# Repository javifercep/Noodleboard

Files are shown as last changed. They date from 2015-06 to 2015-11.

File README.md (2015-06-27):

# Noodleboard
Arduino form factor board with USB 2.0 High speed based on STM32F405 MCU.
It has been developed for the [MuBA project](https://gitlab.euridies.com/javi/MuBA)

## Features
 * STM32F405RGT6 microcontroller featuring 32-bit ARM Cortex-M4F core, 1 MB Flash, 192 KB RAM in an LQFP64 package
 * Extension header fully compatible with Arduino™ form-factor
 * USB3300: USB OTG HS with micro-AB connector
 * Board power supply: through USB bus.
 * External application power supply: 3.3 V and 5 V
 * Four green user LEDs
 * Reset button
 * Headers for programming and debugging through SWD protocol

## [Pin map](pin-map)

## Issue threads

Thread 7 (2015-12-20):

Change USB connector footprint pinout

javifercep, 2015-12-20:
It is inverted

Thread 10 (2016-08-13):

Labels C4 and R5 are swapped

javifercep, 2016-08-13:
Next to the Oscillator of the USB circuit.
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

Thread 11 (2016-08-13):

Lables R22 & R23 are swaped

javifercep, 2016-08-13:
Bottom layer, next to SD connector.
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

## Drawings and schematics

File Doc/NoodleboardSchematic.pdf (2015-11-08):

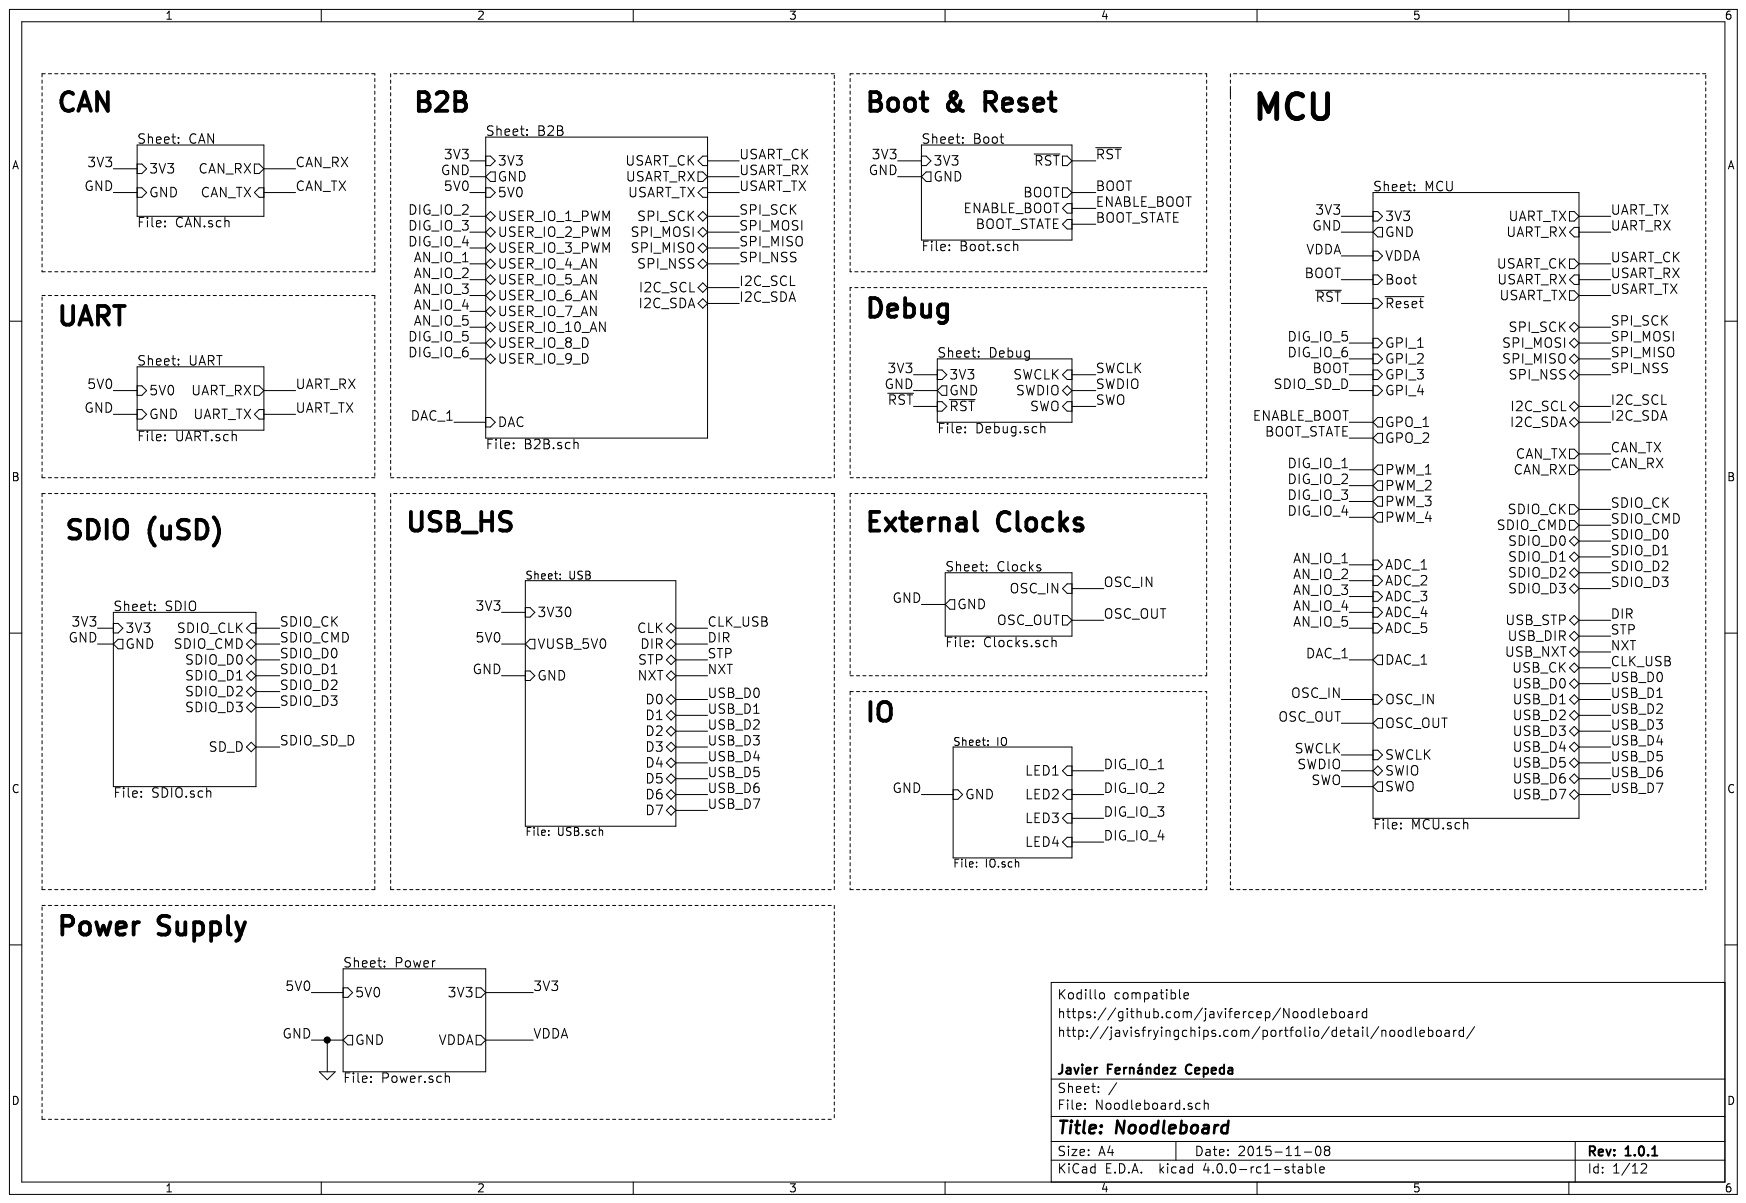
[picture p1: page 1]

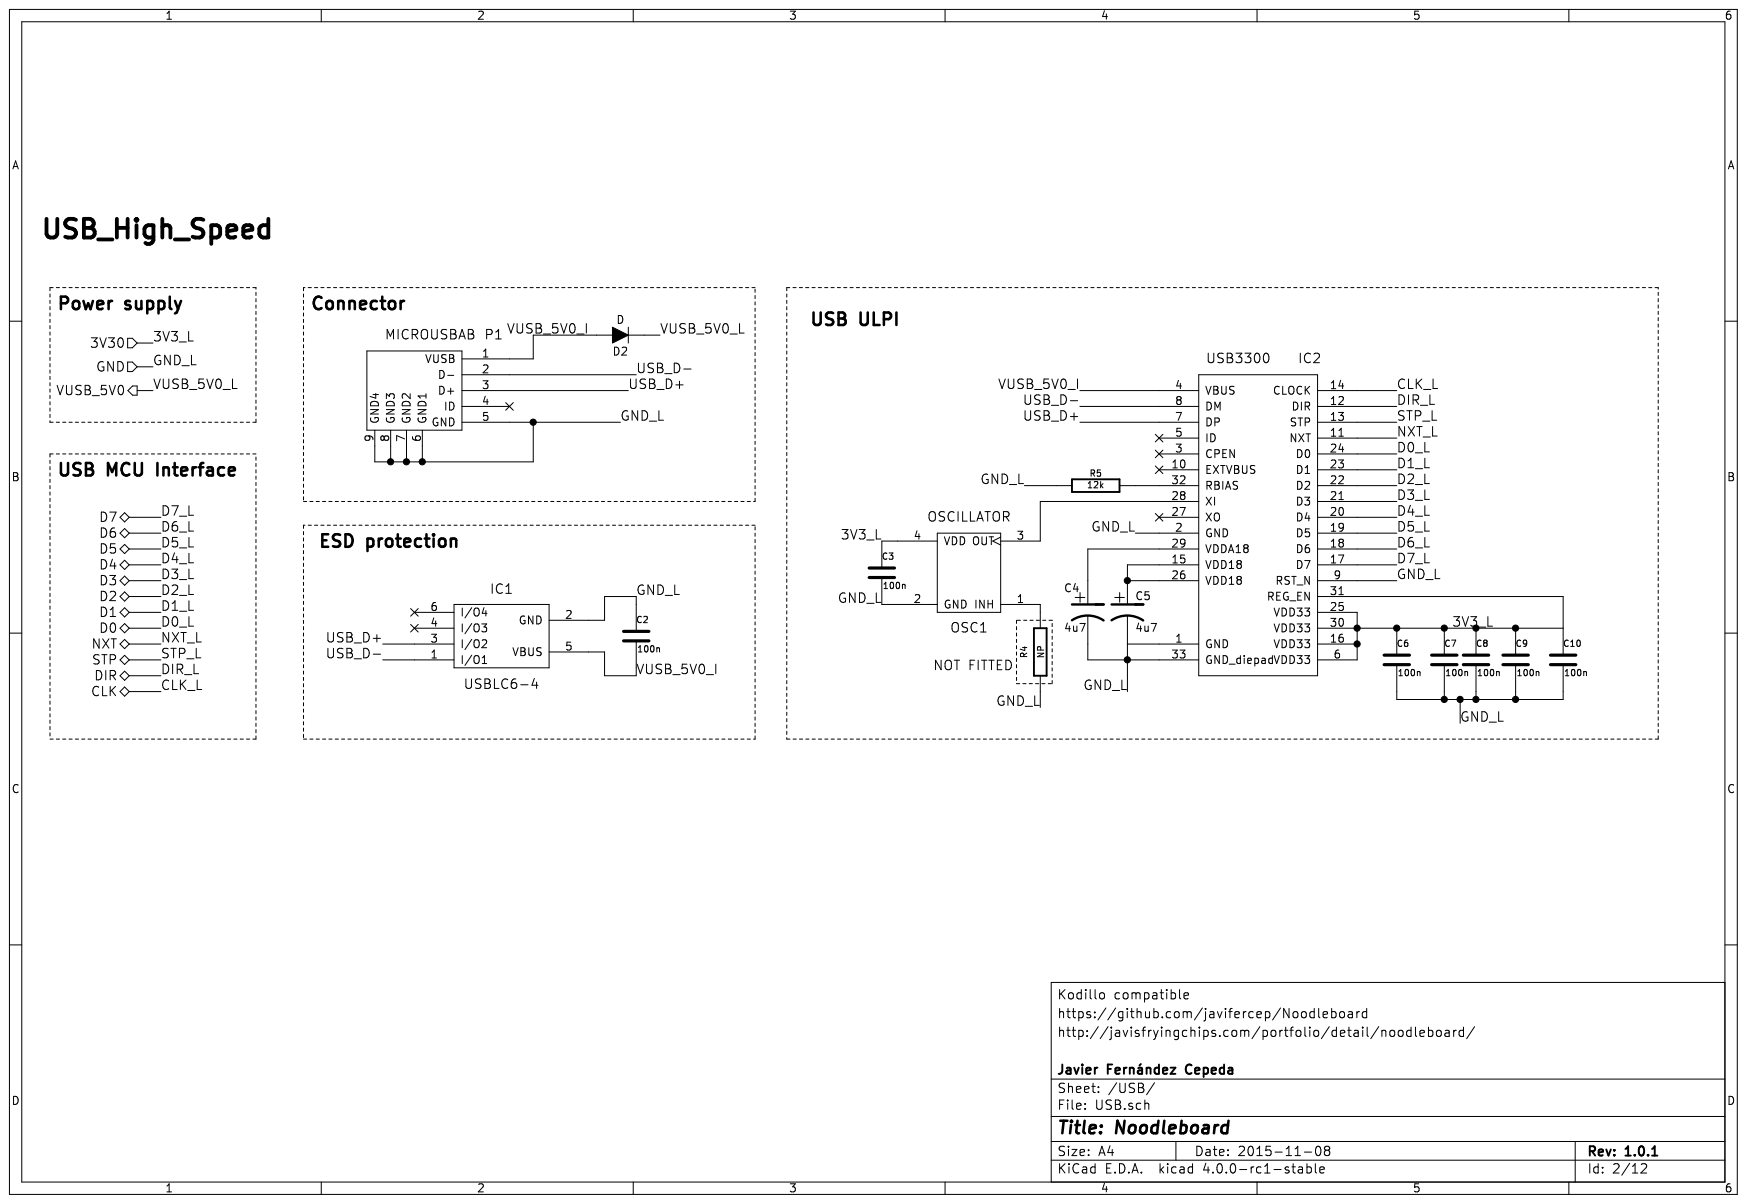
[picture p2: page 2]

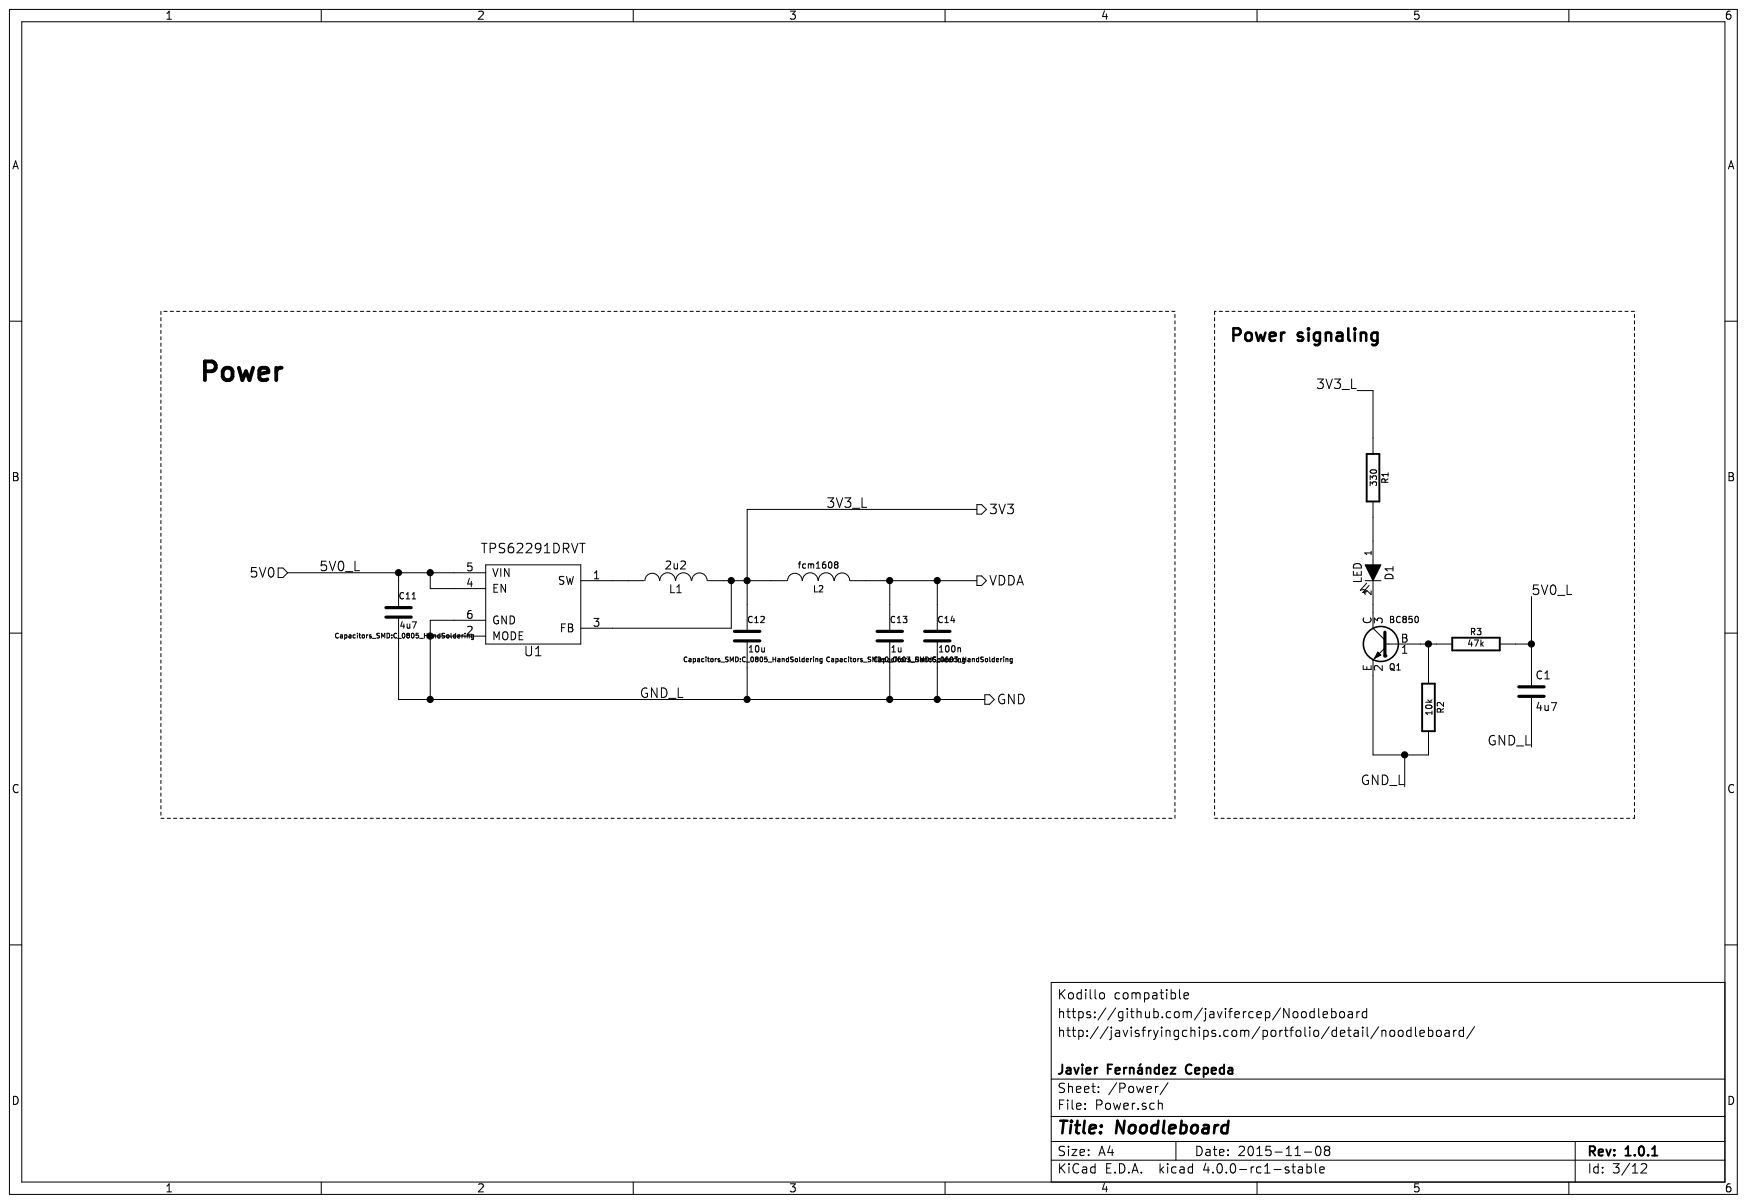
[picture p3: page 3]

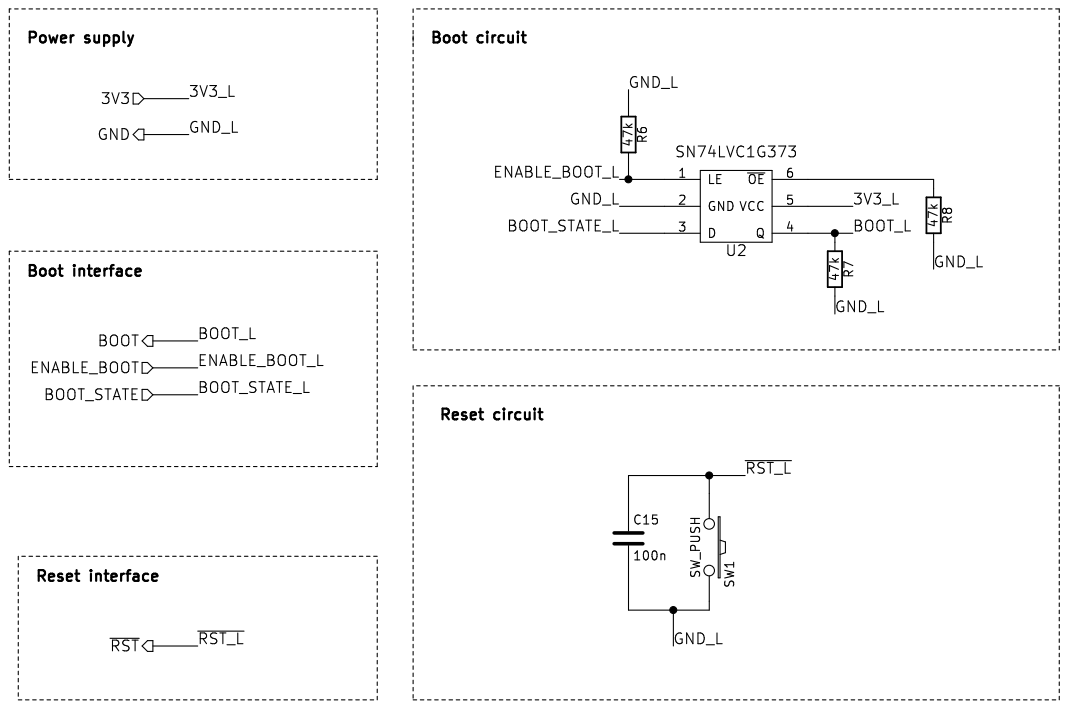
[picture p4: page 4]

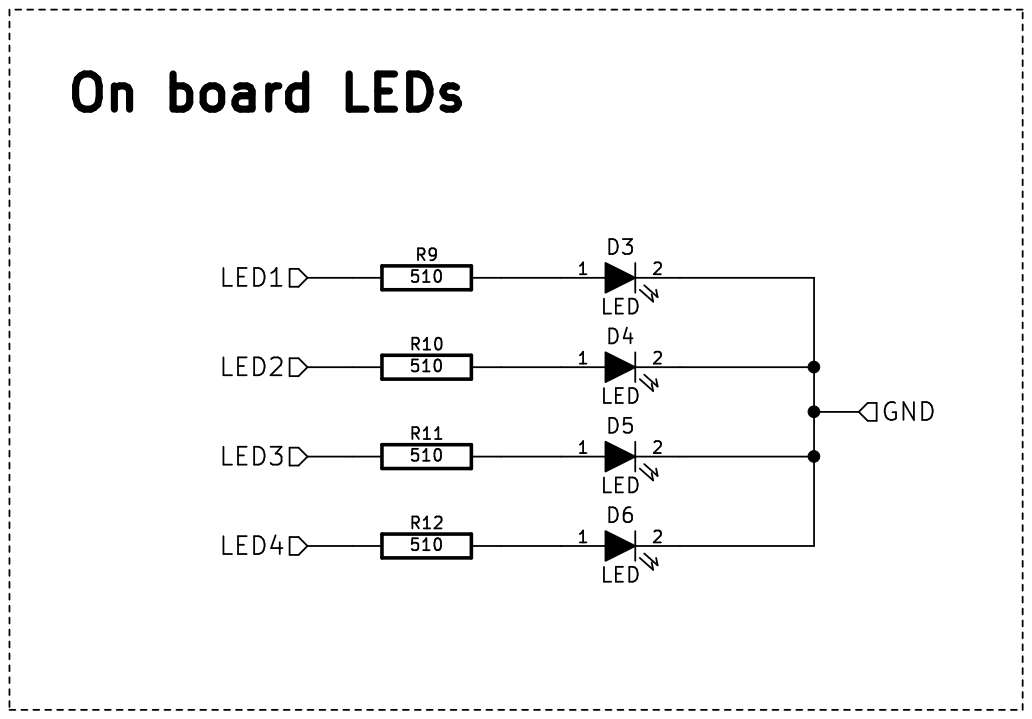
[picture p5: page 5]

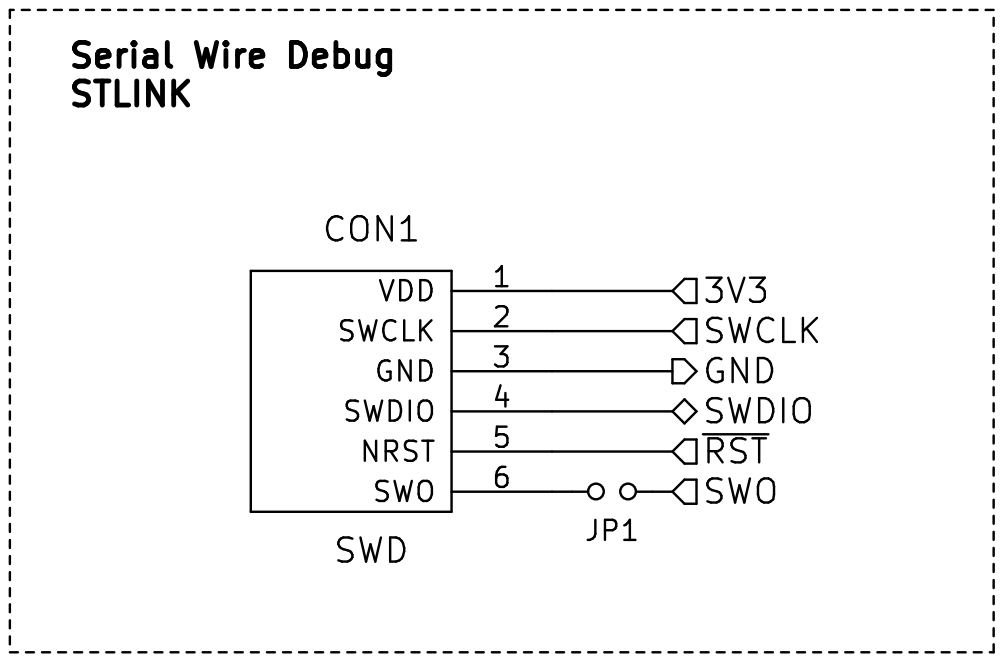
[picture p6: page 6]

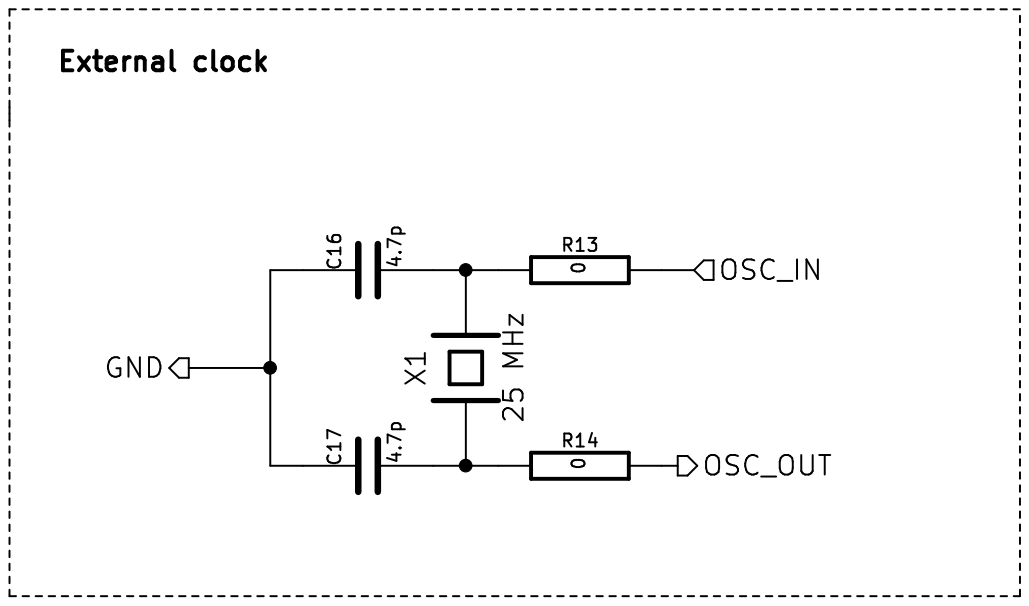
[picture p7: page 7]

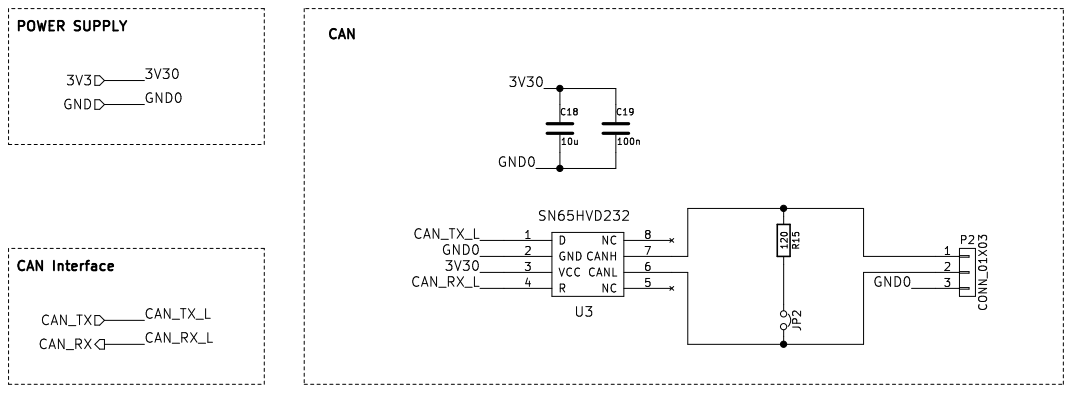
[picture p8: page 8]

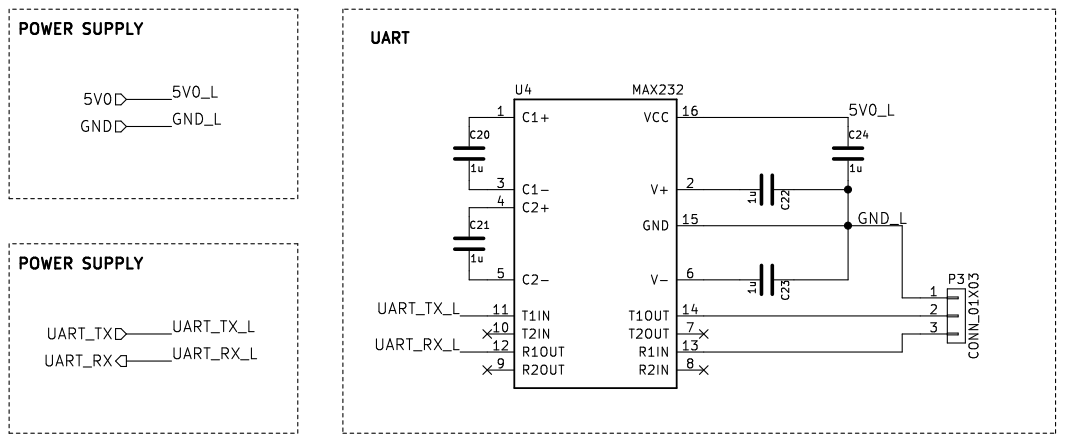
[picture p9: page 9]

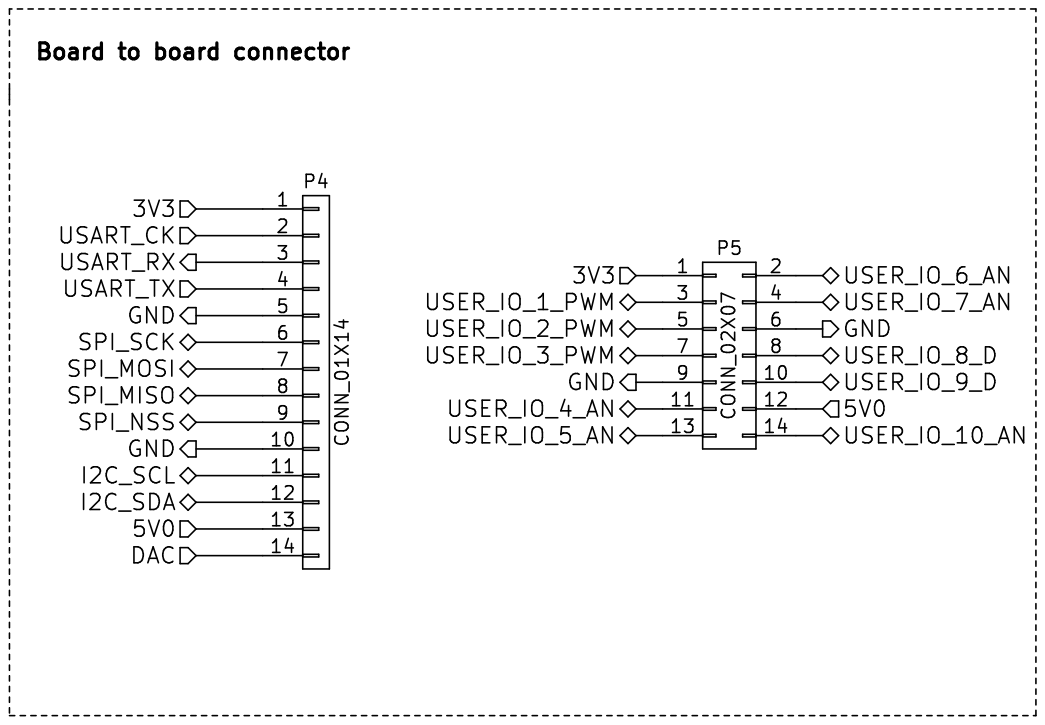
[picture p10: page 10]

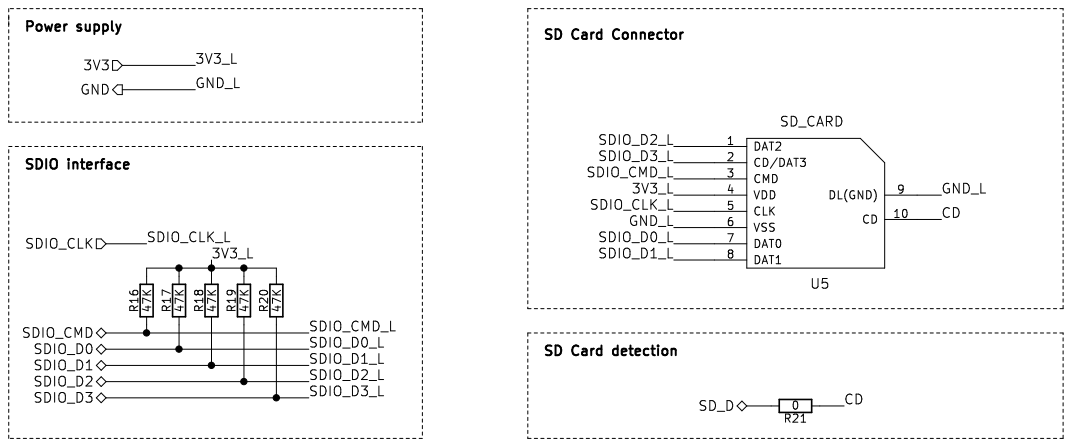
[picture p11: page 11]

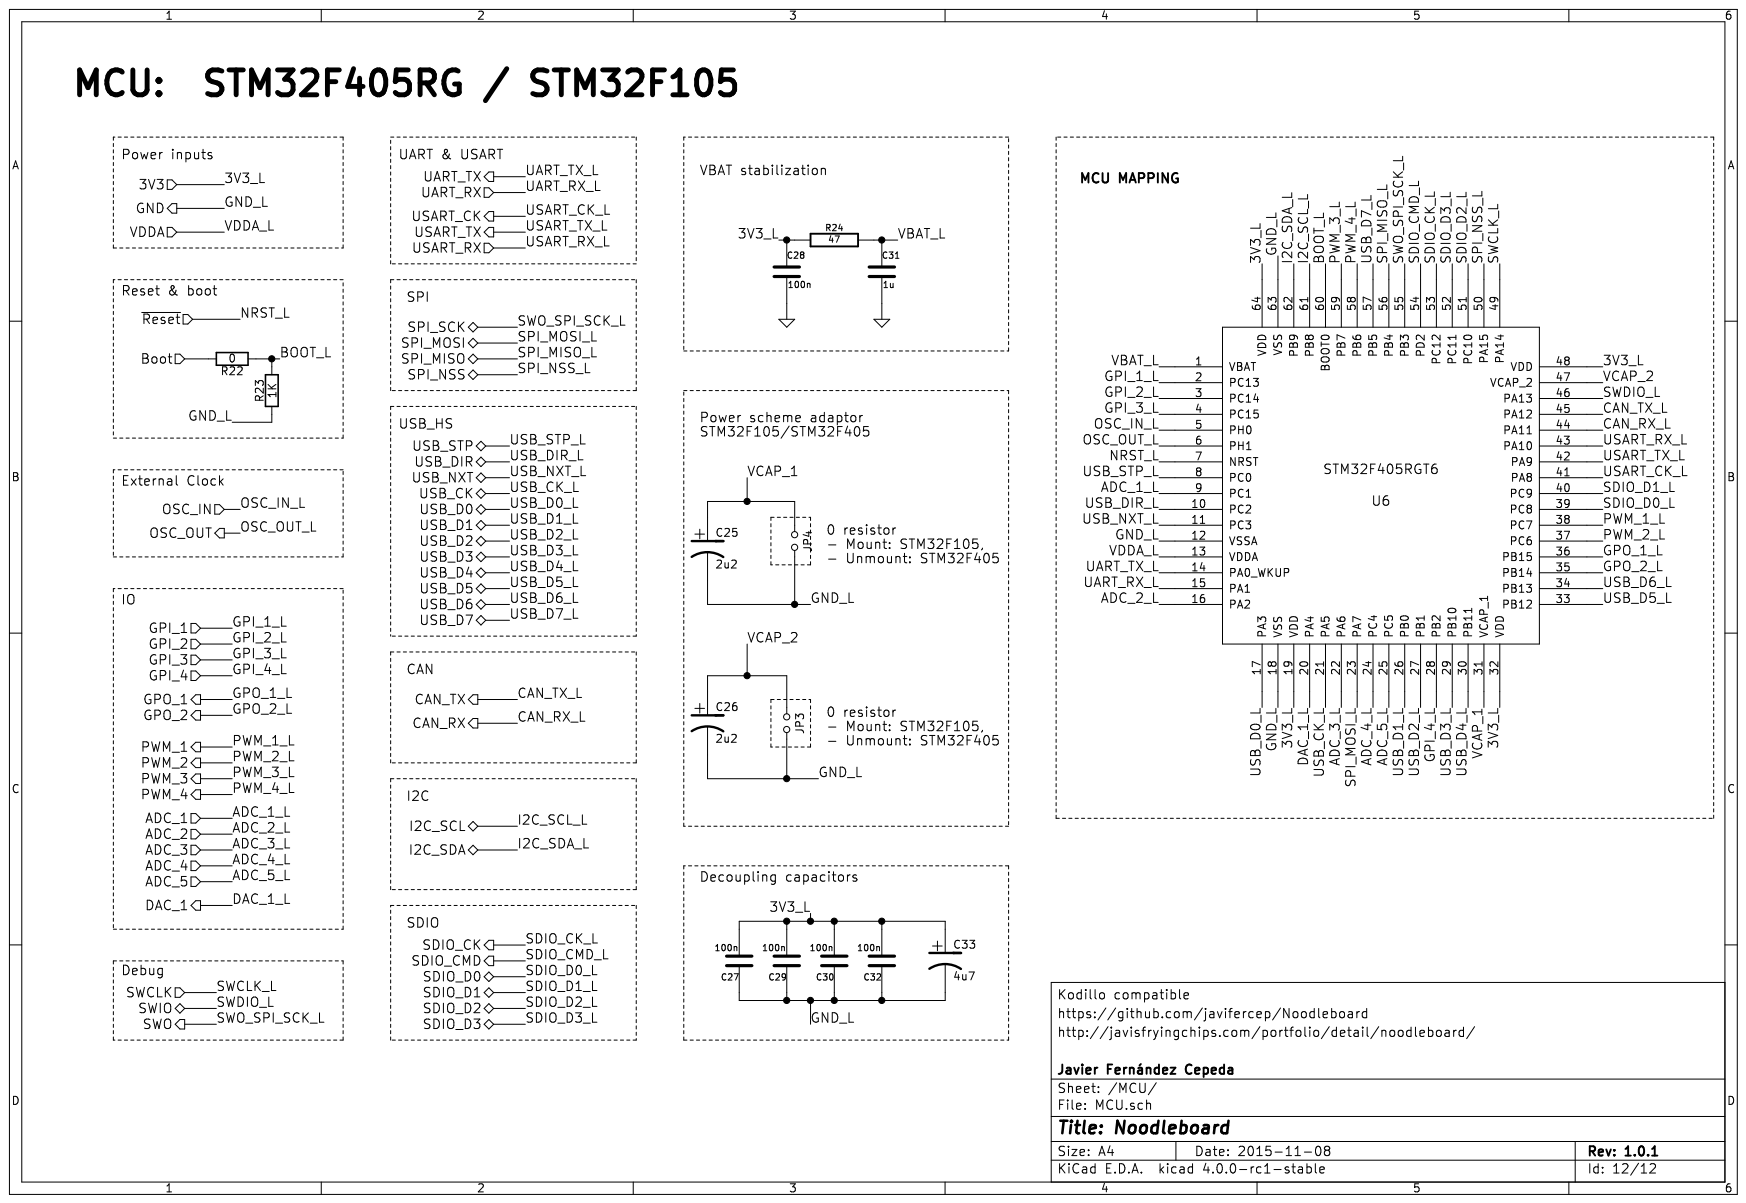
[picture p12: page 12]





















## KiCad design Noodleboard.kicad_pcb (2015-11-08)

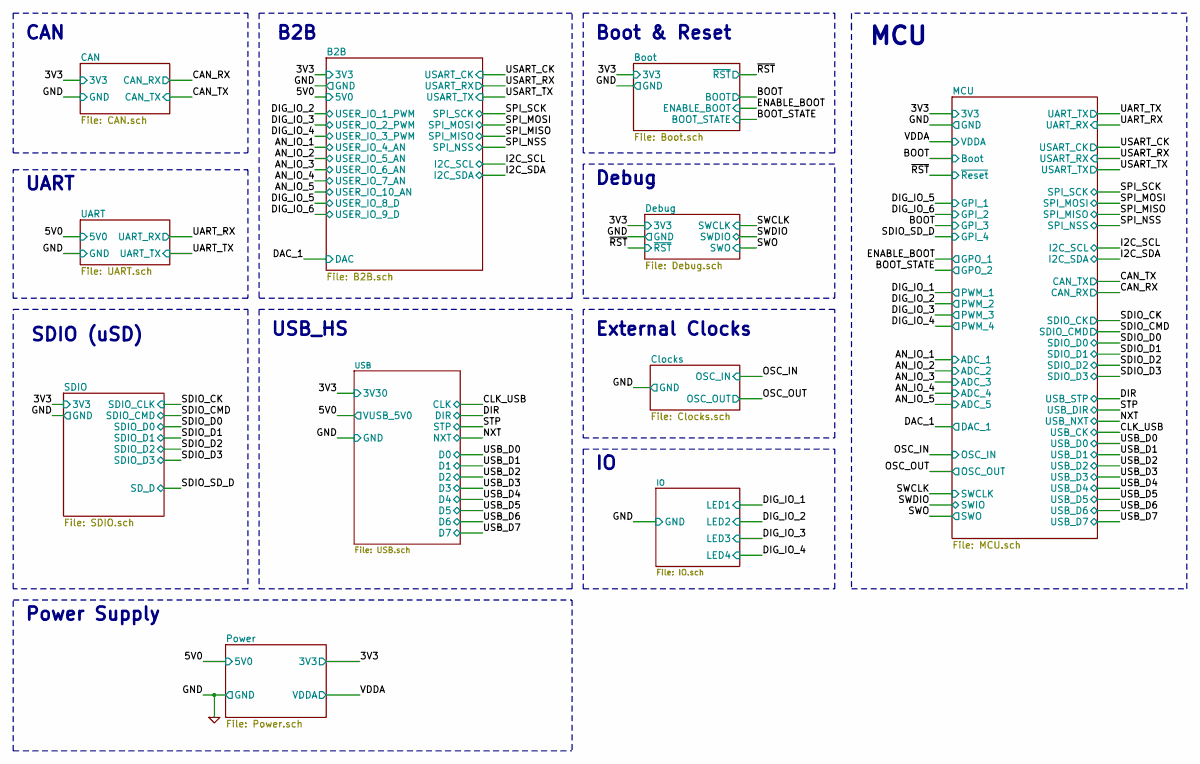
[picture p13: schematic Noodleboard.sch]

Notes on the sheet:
Power Supply
USB_HS
Debug
External Clocks
MCU
Boot & Reset
CAN
UART
B2B
SDIO (uSD)

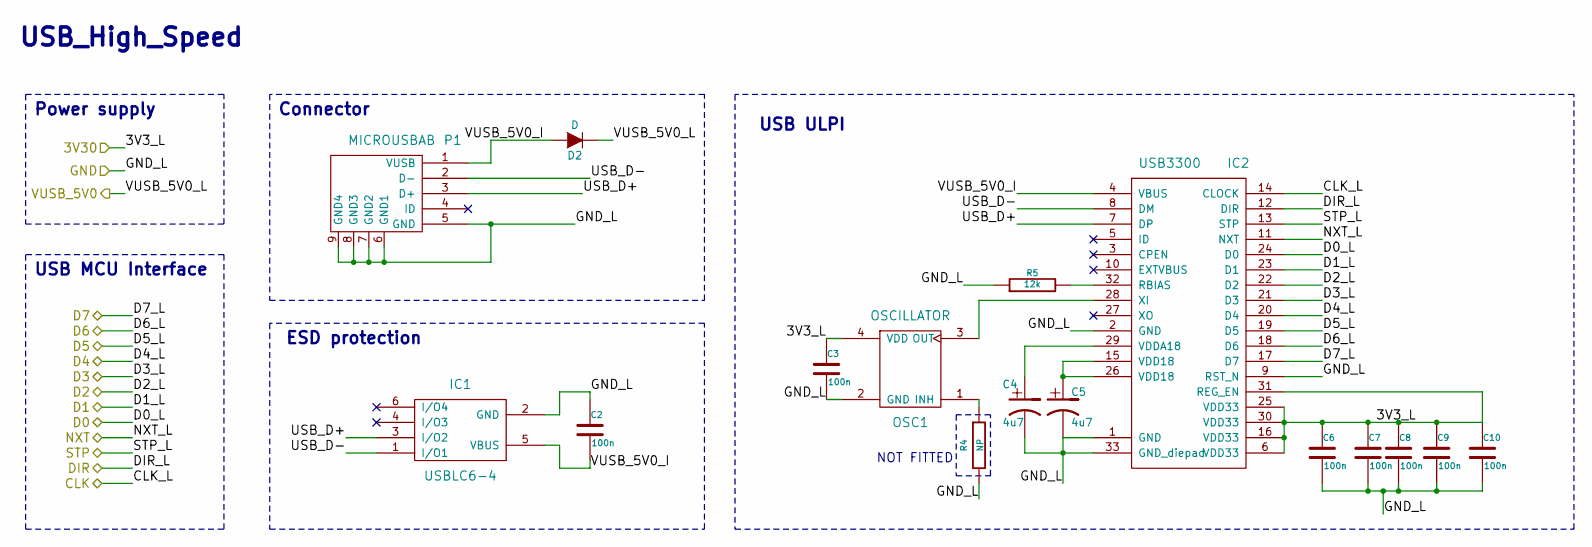
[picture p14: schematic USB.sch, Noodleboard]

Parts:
C2, C3, C6, C7, C8, C9, C10: 100n; C_0603_HandSoldering
C4, C5: 4u7; C_0805_HandSoldering
D2: D; SMA_Handsoldering
IC1: USBLC6-4; SOT-23-6
IC2: USB3300; QFN-32-1EP_5x5mm_Pitch0.5mm
OSC1: OSCILLATOR; 26MHZOSC
P1: MICROUSBAB; uUSB-AB
R4: NP; R_0603_HandSoldering
R5: 12k; R_0603_HandSoldering; Tolerancia 1%

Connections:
/B2B/3V3: C3.1, C6.1, C7.1, C8.1, C9.1, C10.1, IC2.6 (VDD33), IC2.16 (VDD33), IC2.25 (VDD33), IC2.30 (VDD33), IC2.31 (REG_EN), OSC1.4 (VDD); also elsewhere on the board
/B2B/5V0: D2.1 (K); also elsewhere on the board
/USB/CLK: IC2.14 (CLOCK); also elsewhere on the board
/USB/D0: IC2.24 (D0); also elsewhere on the board
/USB/D1: IC2.23 (D1); also elsewhere on the board
/USB/D2: IC2.22 (D2); also elsewhere on the board
/USB/D3: IC2.21 (D3); also elsewhere on the board
/USB/D4: IC2.20 (D4); also elsewhere on the board
/USB/D5: IC2.19 (D5); also elsewhere on the board
/USB/D6: IC2.18 (D6); also elsewhere on the board
/USB/D7: IC2.17 (D7); also elsewhere on the board
/USB/DIR: IC2.12 (DIR); also elsewhere on the board
/USB/NXT: IC2.11 (NXT); also elsewhere on the board
/USB/STP: IC2.13 (STP); also elsewhere on the board
/USB/USB_D+: IC1.3 (I/O2), IC2.7 (DP), P1.3 (D+)
/USB/USB_D-: IC1.1 (I/O1), IC2.8 (DM), P1.2 (D-)
/USB/VUSB_5V0_I: C2.2, D2.2 (A), IC1.5 (VBUS), IC2.4 (VBUS), P1.1 (VUSB)
GND: C2.1, C3.2, C4.2, C5.2, C6.2, C7.2, C8.2, C9.2, C10.2, IC1.2 (GND), IC2.1 (GND), IC2.2 (GND), IC2.9 (RST_N), IC2.33 (GND_diepad), OSC1.2 (GND), P1.5 (GND), P1.6 (GND1), P1.7 (GND2), P1.8 (GND3), P1.9 (GND4), R4.2, R5.1; also elsewhere on the board
unnamed: C4.1, IC2.29 (VDDA18)
unnamed: C5.1, IC2.15 (VDD18), IC2.26 (VDD18)
unnamed: IC2.28 (XI), OSC1.3 (OUT)
unnamed: IC2.32 (RBIAS), R5.2
unnamed: OSC1.1 (INH), R4.1

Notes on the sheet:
Power supply
USB_High_Speed
NOT FITTED
Connector
ESD protection
USB MCU Interface
USB ULPI

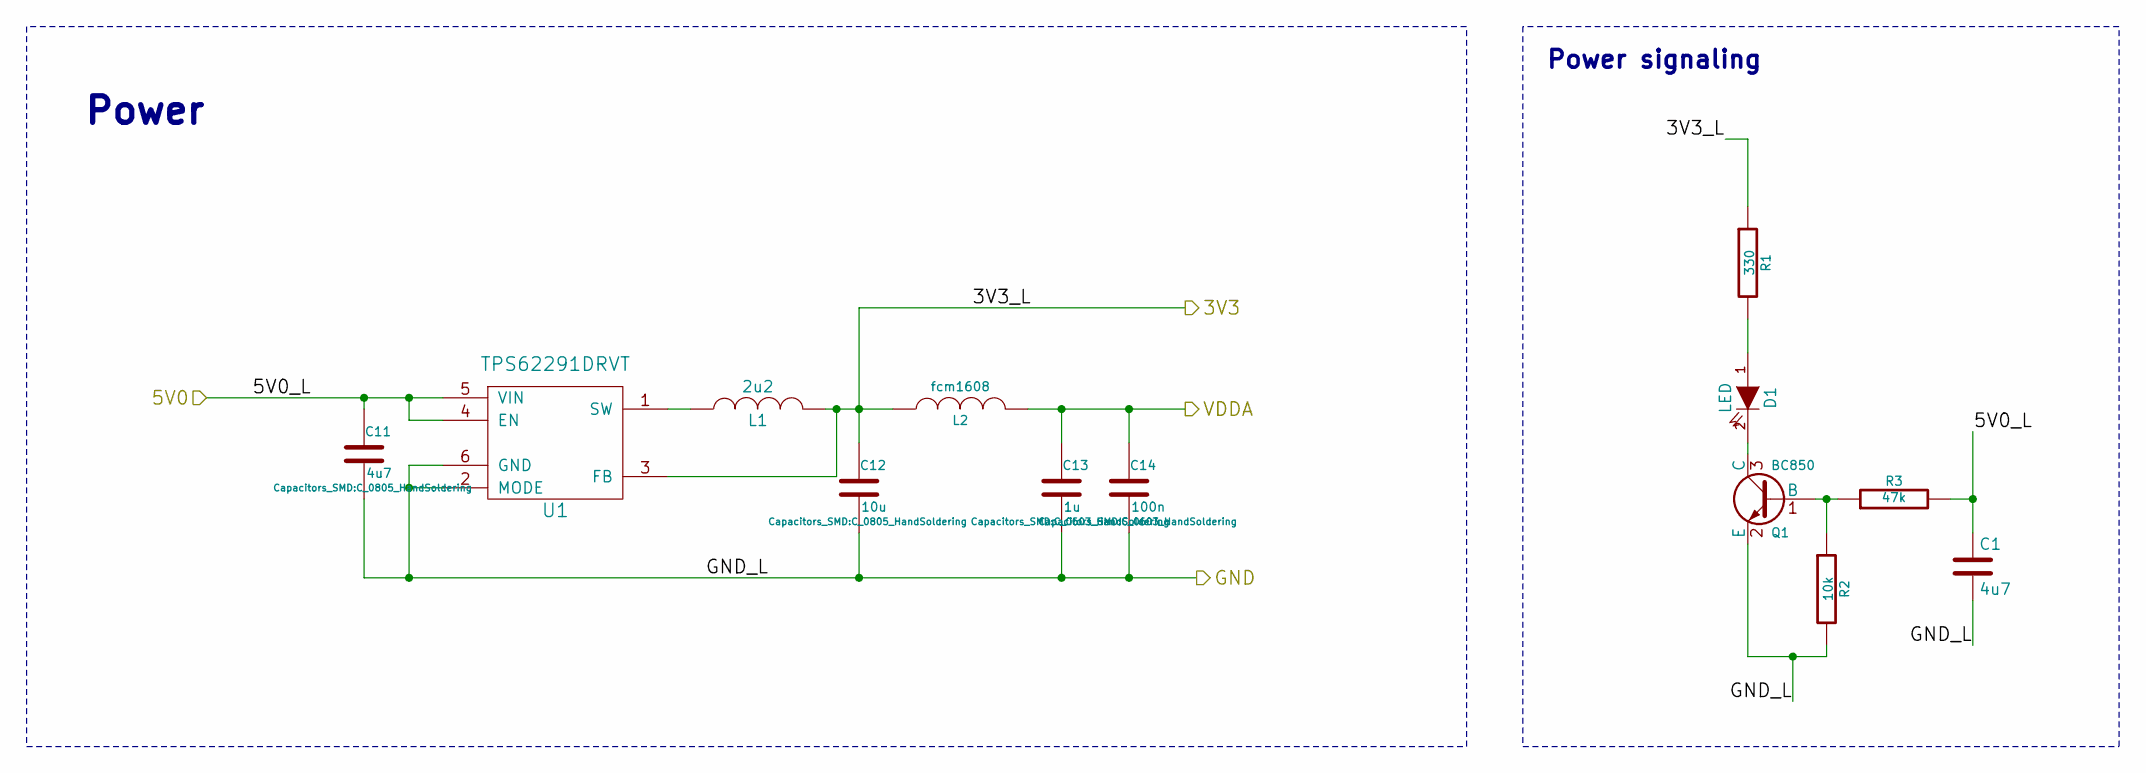
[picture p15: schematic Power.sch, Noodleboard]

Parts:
C1: 4u7; C_0805_HandSoldering
C11: 4u7; C_0805_HandSoldering; Part Number GRM188R60J475KE19D
C12: 10u; C_0805_HandSoldering; Part Number C1608X5R0J106M
C13: 1u; C_0603_HandSoldering
C14: 100n; C_0603_HandSoldering
D1: LED; LED-0805
L1: 2u2; SMD_1008; Part Number 74479887222A
L2: fcm1608; R_0603_HandSoldering
Q1: BC850; SOT-23_Handsoldering
R1: 330; R_0603_HandSoldering
R2: 10k; R_0603_HandSoldering
R3: 47k; R_0603_HandSoldering
U1: TPS62291DRVT; S-PWSON-N6

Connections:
/B2B/3V3: C12.1, L1.2, L2.1, R1.1, U1.3 (FB); also elsewhere on the board
/B2B/5V0: C1.1, C11.1, R3.2, U1.4 (EN), U1.5 (VIN); also elsewhere on the board
/MCU/VDDA: C13.1, C14.1, L2.2; also elsewhere on the board
GND: C1.2, C11.2, C12.2, C13.2, C14.2, Q1.2 (E), R2.2, U1.2 (MODE), U1.6 (GND); also elsewhere on the board
unnamed: D1.1 (A), R1.2
unnamed: D1.2 (K), Q1.3 (C)
unnamed: L1.1, U1.1 (SW)
unnamed: Q1.1 (B), R2.1, R3.1

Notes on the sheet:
Power
Power signaling

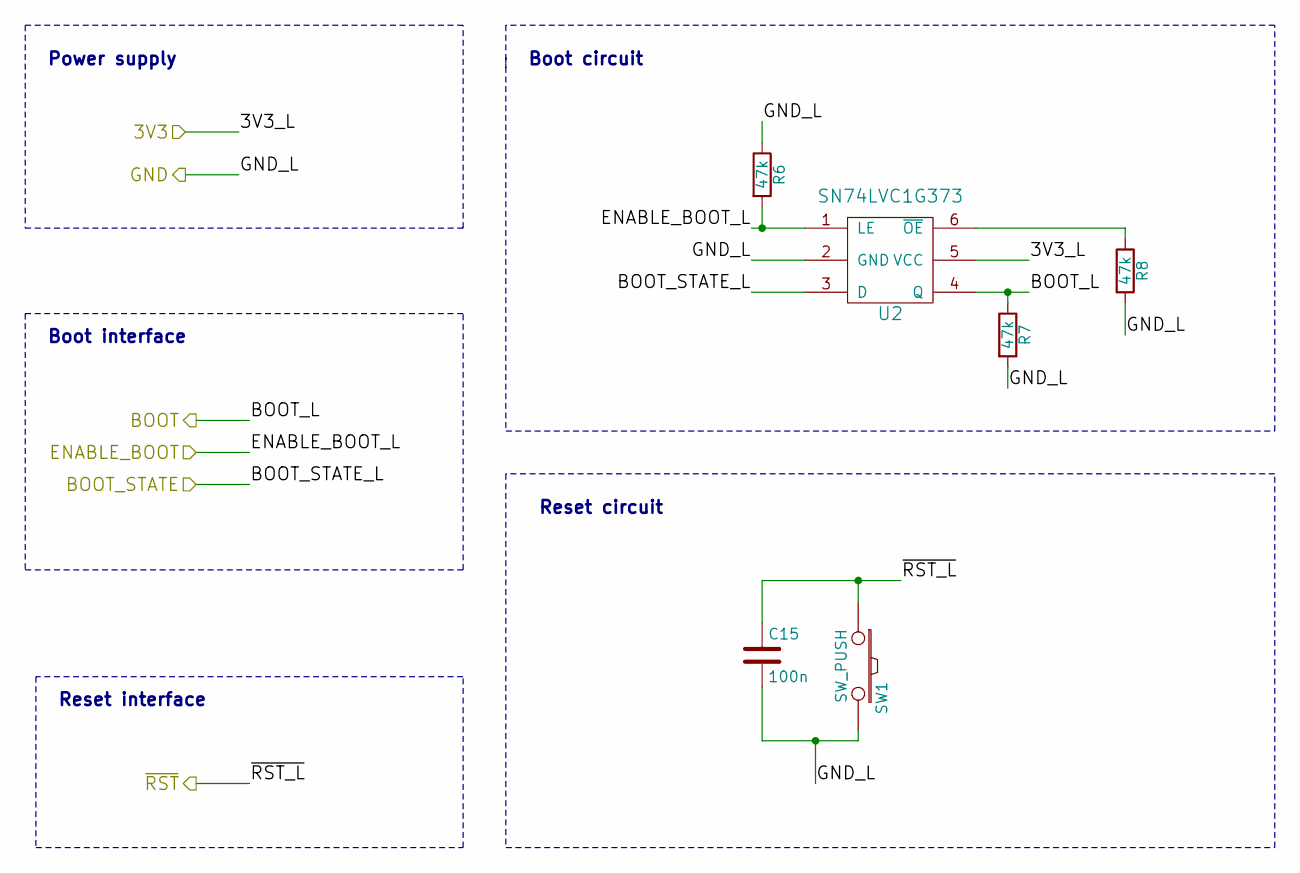
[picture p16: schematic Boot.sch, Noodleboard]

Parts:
C15: 100n; C_0603_HandSoldering
R6, R7, R8: 47k; R_0603_HandSoldering
SW1: SW_PUSH; SW_PUSH_SMALL_SMD
U2: SN74LVC1G373; SOT-23-6

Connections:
/B2B/3V3: U2.5 (VCC); also elsewhere on the board
/Boot/BOOT: R7.1, U2.4 (Q); also elsewhere on the board
/Boot/BOOT_STATE: U2.3 (D); also elsewhere on the board
/Boot/ENABLE_BOOT: R6.2, U2.1 (LE); also elsewhere on the board
/Boot/~RST: C15.1, SW1.1; also elsewhere on the board
GND: C15.2, R6.1, R7.2, R8.2, SW1.2, U2.2 (GND); also elsewhere on the board
unnamed: R8.1, U2.6 (~OE)

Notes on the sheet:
Reset circuit
Boot circuit
Power supply
Boot interface
Reset interface

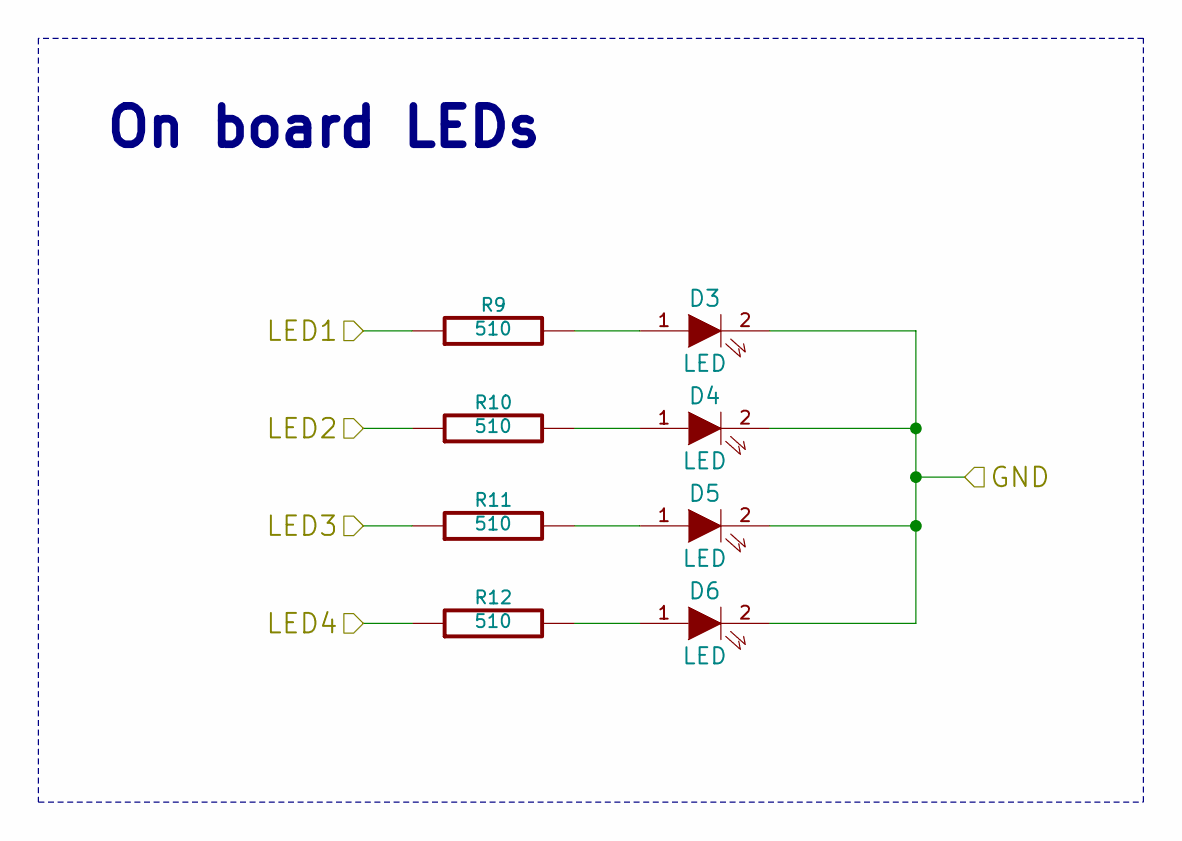
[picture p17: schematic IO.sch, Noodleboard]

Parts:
D3, D4, D5, D6: LED; LED-0805
R9, R10, R11, R12: 510; R_0603_HandSoldering

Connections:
/IO/LED1: R9.1; also elsewhere on the board
/IO/LED2: R10.1; also elsewhere on the board
/IO/LED3: R11.1; also elsewhere on the board
/IO/LED4: R12.1; also elsewhere on the board
GND: D3.2 (K), D4.2 (K), D5.2 (K), D6.2 (K); also elsewhere on the board
unnamed: D3.1 (A), R9.2
unnamed: D4.1 (A), R10.2
unnamed: D5.1 (A), R11.2
unnamed: D6.1 (A), R12.2

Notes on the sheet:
On board LEDs

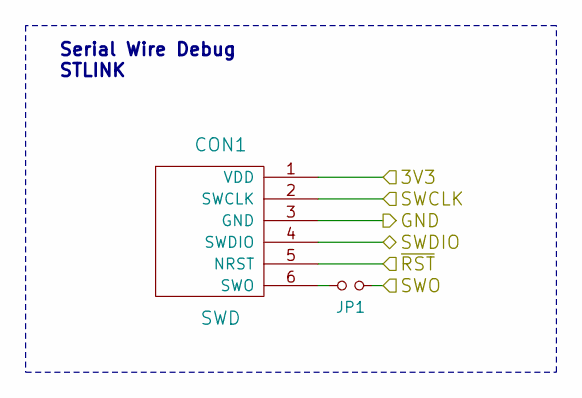
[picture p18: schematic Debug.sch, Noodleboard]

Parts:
CON1: SWD; Pin_Header_Straight_1x06
JP1: Jumper_NO_Small; R_0603_HandSoldering

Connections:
/B2B/3V3: CON1.1 (VDD); also elsewhere on the board
/B2B/SPI_SCK: JP1.2; also elsewhere on the board
/Boot/~RST: CON1.5 (NRST); also elsewhere on the board
/Debug/SWCLK: CON1.2 (SWCLK); also elsewhere on the board
/Debug/SWDIO: CON1.4 (SWDIO); also elsewhere on the board
GND: CON1.3 (GND); also elsewhere on the board
unnamed: CON1.6 (SWO), JP1.1

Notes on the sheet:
Serial Wire Debug STLINK

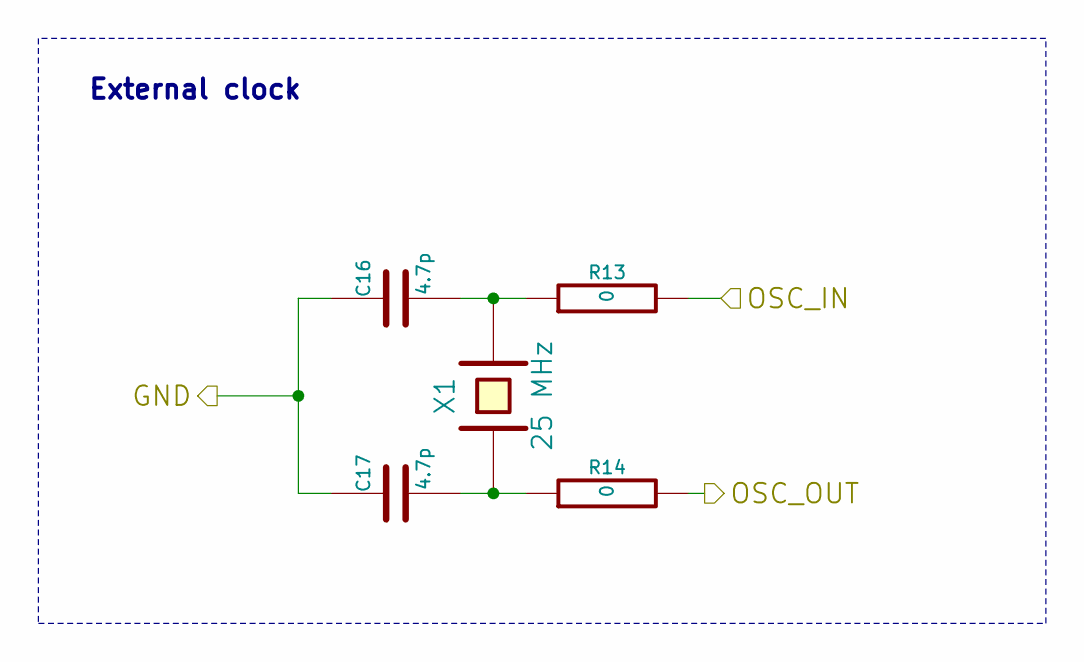
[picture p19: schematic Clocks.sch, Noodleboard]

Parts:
C16, C17: 4.7p; C_0603_HandSoldering
R13, R14: 0; R_0603_HandSoldering
X1: 25 MHz; 7A-25.000MAAJ-T

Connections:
/Clocks/OSC_IN: R13.2; also elsewhere on the board
/Clocks/OSC_OUT: R14.2; also elsewhere on the board
GND: C16.1, C17.1; also elsewhere on the board
unnamed: C16.2, R13.1, X1.2
unnamed: C17.2, R14.1, X1.1

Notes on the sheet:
External clock

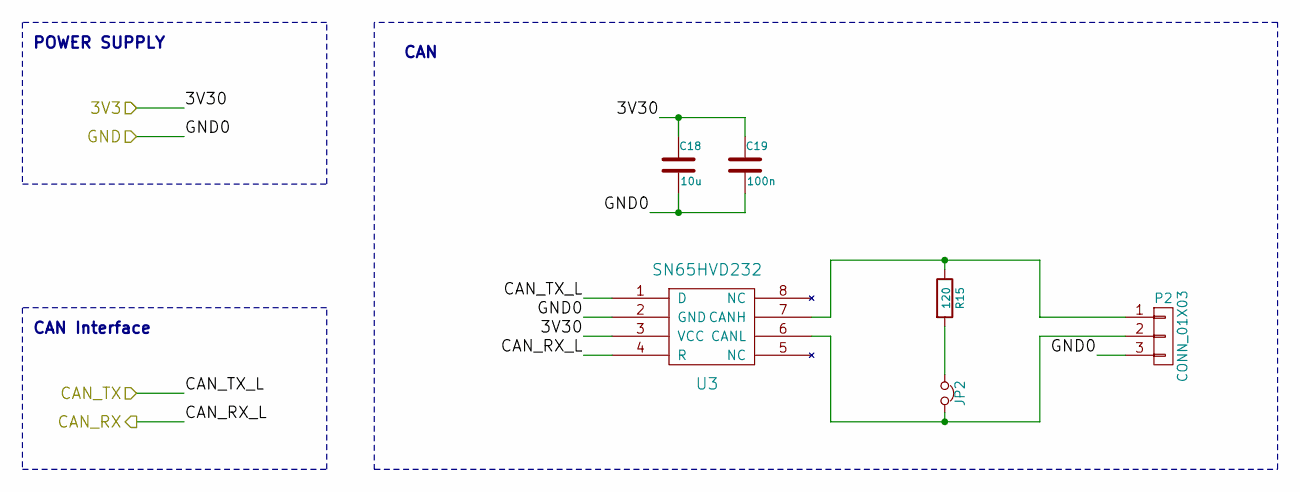
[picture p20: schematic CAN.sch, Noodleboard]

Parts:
C18: 10u; C_0805_HandSoldering
C19: 100n; C_0603_HandSoldering
JP2: Jumper_NC_Small; AYZ-SlideSwitches
P2: CONN_01X03; Pin_Header_Straight_1x03
R15: 120; R_0805_HandSoldering
U3: SN65HVD232; SOIC-8_3.9x4.9mm_Pitch1.27mm

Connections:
/B2B/3V3: C18.1, C19.1, U3.3 (VCC); also elsewhere on the board
/CAN/CAN_RX: U3.4 (R); also elsewhere on the board
/CAN/CAN_TX: U3.1 (D); also elsewhere on the board
GND: C18.2, C19.2, P2.3, U3.2 (GND); also elsewhere on the board
unnamed: JP2.1, R15.2
unnamed: JP2.2, P2.2, U3.6 (CANL)
unnamed: P2.1, R15.1, U3.7 (CANH)

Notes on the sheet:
POWER SUPPLY
CAN
CAN Interface

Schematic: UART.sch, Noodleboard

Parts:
C20, C21, C22, C23, C24: 1u; C_0603_HandSoldering
P3: CONN_01X03; Pin_Header_Straight_1x03
U4: MAX232; SOIC-16_3.9x9.9mm_Pitch1.27mm

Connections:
/B2B/5V0: C24.1, U4.16 (VCC); also elsewhere on the board
/MCU/UART_RX: U4.12 (R1OUT); also elsewhere on the board
/MCU/UART_TX: U4.11 (T1IN); also elsewhere on the board
GND: C22.1, C23.1, C24.2, P3.1, U4.15 (GND); also elsewhere on the board
unnamed: C20.1, U4.1 (C1+)
unnamed: C20.2, U4.3 (C1-)
unnamed: C21.1, U4.4 (C2+)
unnamed: C21.2, U4.5 (C2-)
unnamed: C22.2, U4.2 (V+)
unnamed: C23.2, U4.6 (V-)
unnamed: P3.2, U4.14 (T1OUT)
unnamed: P3.3, U4.13 (R1IN)

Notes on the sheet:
POWER SUPPLY
UART

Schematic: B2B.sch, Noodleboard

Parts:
P4: CONN_01X14; Pin_Header_Straight_1x14
P5: CONN_02X07; Pin_Header_Straight_2x07

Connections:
/B2B/3V3: P4.1, P5.1; also elsewhere on the board
/B2B/5V0: P4.13, P5.12; also elsewhere on the board
/B2B/DAC: P4.14; also elsewhere on the board
/B2B/I2C_SCL: P4.11; also elsewhere on the board
/B2B/I2C_SDA: P4.12; also elsewhere on the board
/B2B/SPI_MISO: P4.8; also elsewhere on the board
/B2B/SPI_MOSI: P4.7; also elsewhere on the board
/B2B/SPI_NSS: P4.9; also elsewhere on the board
/B2B/SPI_SCK: P4.6; also elsewhere on the board
/B2B/USART_CK: P4.2; also elsewhere on the board
/B2B/USART_RX: P4.3; also elsewhere on the board
/B2B/USART_TX: P4.4; also elsewhere on the board
/IO/LED2: P5.3; also elsewhere on the board
/IO/LED3: P5.5; also elsewhere on the board
/IO/LED4: P5.7; also elsewhere on the board
/MCU/ADC_1: P5.11; also elsewhere on the board
/MCU/ADC_2: P5.13; also elsewhere on the board
/MCU/ADC_3: P5.2; also elsewhere on the board
/MCU/ADC_4: P5.4; also elsewhere on the board
/MCU/ADC_5: P5.14; also elsewhere on the board
/MCU/GPI_1: P5.8; also elsewhere on the board
/MCU/GPI_2: P5.10; also elsewhere on the board
GND: P4.5, P4.10, P5.6, P5.9; also elsewhere on the board

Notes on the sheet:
Board to board connector

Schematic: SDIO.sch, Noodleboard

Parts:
R16, R17, R18, R19, R20: 47K; R_0603_HandSoldering
R21: 0; R_0603_HandSoldering
U5: SD_CARD; uSDCard

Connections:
/B2B/3V3: R16.2, R17.2, R18.2, R19.2, R20.2, U5.4 (VDD); also elsewhere on the board
/MCU/GPI_4: R21.2; also elsewhere on the board
/MCU/SDIO_CK: U5.5 (CLK); also elsewhere on the board
/MCU/SDIO_CMD: R16.1, U5.3 (CMD); also elsewhere on the board
/MCU/SDIO_D0: R17.1, U5.7 (DAT0); also elsewhere on the board
/MCU/SDIO_D1: R18.1, U5.8 (DAT1); also elsewhere on the board
/MCU/SDIO_D2: R19.1, U5.1 (DAT2); also elsewhere on the board
/MCU/SDIO_D3: R20.1, U5.2 (CD/DAT3); also elsewhere on the board
/SDIO/CD: R21.1, U5.10 (CD)
GND: U5.6 (VSS), U5.9 (DL(GND)); also elsewhere on the board

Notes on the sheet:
SD Card Connector
Power supply
SDIO interface
SD Card detection

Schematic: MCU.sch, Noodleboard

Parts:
C25, C26: 2u2; C_0805_HandSoldering
C27, C28, C29, C30, C32: 100n; C_0603_HandSoldering
C31: 1u; C_0603_HandSoldering
C33: 4u7; C_0805_HandSoldering
JP3, JP4: Jumper_NO_Small; R_0603_HandSoldering
R22: 0; R_0603_HandSoldering
R23: 1K; R_0603_HandSoldering
R24: 47; R_0603_HandSoldering
U6: STM32F405RGT6; LQFP-64_10x10mm_Pitch0.5mm

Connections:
/B2B/3V3: C27.2, C28.1, C29.2, C30.2, C32.2, C33.1, R24.1, U6.19 (VDD), U6.32 (VDD), U6.48 (VDD), U6.64 (VDD); also elsewhere on the board
/B2B/DAC: U6.20 (PA4); also elsewhere on the board
/B2B/I2C_SCL: U6.61 (PB8); also elsewhere on the board
/B2B/I2C_SDA: U6.62 (PB9); also elsewhere on the board
/B2B/SPI_MISO: U6.56 (PB4); also elsewhere on the board
/B2B/SPI_MOSI: U6.23 (PA7); also elsewhere on the board
/B2B/SPI_NSS: U6.50 (PA15); also elsewhere on the board
/B2B/SPI_SCK: U6.55 (PB3); also elsewhere on the board
/B2B/USART_CK: U6.41 (PA8); also elsewhere on the board
/B2B/USART_RX: U6.43 (PA10); also elsewhere on the board
/B2B/USART_TX: U6.42 (PA9); also elsewhere on the board
/Boot/BOOT: R22.2, U6.4 (PC15); also elsewhere on the board
/Boot/BOOT_STATE: U6.35 (PB14); also elsewhere on the board
/Boot/ENABLE_BOOT: U6.36 (PB15); also elsewhere on the board
/Boot/~RST: U6.7 (NRST); also elsewhere on the board
/CAN/CAN_RX: U6.44 (PA11); also elsewhere on the board
/CAN/CAN_TX: U6.45 (PA12); also elsewhere on the board
/Clocks/OSC_IN: U6.5 (PH0); also elsewhere on the board
/Clocks/OSC_OUT: U6.6 (PH1); also elsewhere on the board
/Debug/SWCLK: U6.49 (PA14); also elsewhere on the board
/Debug/SWDIO: U6.46 (PA13); also elsewhere on the board
/IO/LED1: U6.38 (PC7); also elsewhere on the board
/IO/LED2: U6.37 (PC6); also elsewhere on the board
/IO/LED3: U6.59 (PB7); also elsewhere on the board
/IO/LED4: U6.58 (PB6); also elsewhere on the board
/MCU/ADC_1: U6.9 (PC1); also elsewhere on the board
/MCU/ADC_2: U6.16 (PA2); also elsewhere on the board
/MCU/ADC_3: U6.22 (PA6); also elsewhere on the board
/MCU/ADC_4: U6.24 (PC4); also elsewhere on the board
/MCU/ADC_5: U6.25 (PC5); also elsewhere on the board
/MCU/BOOT_L: R22.1, R23.2, U6.60 (BOOT0)
/MCU/GPI_1: U6.2 (PC13); also elsewhere on the board
/MCU/GPI_2: U6.3 (PC14); also elsewhere on the board
/MCU/GPI_4: U6.28 (PB2); also elsewhere on the board
/MCU/SDIO_CK: U6.53 (PC12); also elsewhere on the board
/MCU/SDIO_CMD: U6.54 (PD2); also elsewhere on the board
/MCU/SDIO_D0: U6.39 (PC8); also elsewhere on the board
/MCU/SDIO_D1: U6.40 (PC9); also elsewhere on the board
/MCU/SDIO_D2: U6.51 (PC10); also elsewhere on the board
/MCU/SDIO_D3: U6.52 (PC11); also elsewhere on the board
/MCU/UART_RX: U6.15 (PA1); also elsewhere on the board
/MCU/UART_TX: U6.14 (PA0_WKUP); also elsewhere on the board
/MCU/VBAT_L: C31.1, R24.2, U6.1 (VBAT)
/MCU/VCAP_1: C25.1, JP4.1, U6.31 (VCAP_1)
/MCU/VCAP_2: C26.1, JP3.1, U6.47 (VCAP_2)
/MCU/VDDA: U6.13 (VDDA); also elsewhere on the board
/USB/CLK: U6.21 (PA5); also elsewhere on the board
/USB/D0: U6.17 (PA3); also elsewhere on the board
/USB/D1: U6.26 (PB0); also elsewhere on the board
/USB/D2: U6.27 (PB1); also elsewhere on the board
/USB/D3: U6.29 (PB10); also elsewhere on the board
/USB/D4: U6.30 (PB11); also elsewhere on the board
/USB/D5: U6.33 (PB12); also elsewhere on the board
/USB/D6: U6.34 (PB13); also elsewhere on the board
/USB/D7: U6.57 (PB5); also elsewhere on the board
/USB/DIR: U6.8 (PC0); also elsewhere on the board
/USB/NXT: U6.11 (PC3); also elsewhere on the board
/USB/STP: U6.10 (PC2); also elsewhere on the board
GND: C25.2, C26.2, C27.1, C28.2, C29.1, C30.1, C31.2, C32.1, C33.2, JP3.2, JP4.2, R23.1, U6.12 (VSSA), U6.18 (VSS), U6.63 (VSS); also elsewhere on the board

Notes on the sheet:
MCU: STM32F405RG / STM32F105
0 resistor - Mount: STM32F105, - Unmount: STM32F405
Power inputs
Decoupling capacitors
Reset & boot
External Clock
USB_HS
Debug
UART & USART
SPI
CAN
I2C
SDIO
MCU MAPPING
Power scheme adaptor STM32F105/STM32F405
VBAT stabilization

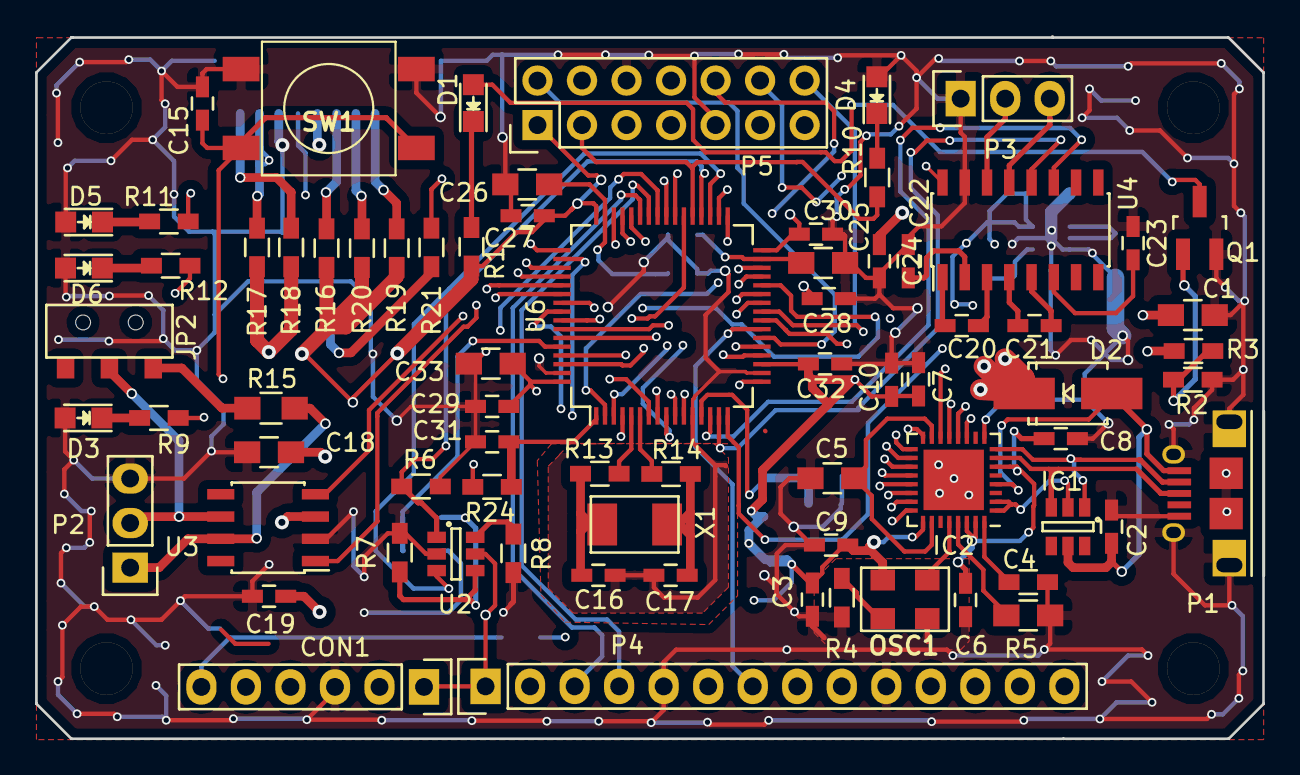
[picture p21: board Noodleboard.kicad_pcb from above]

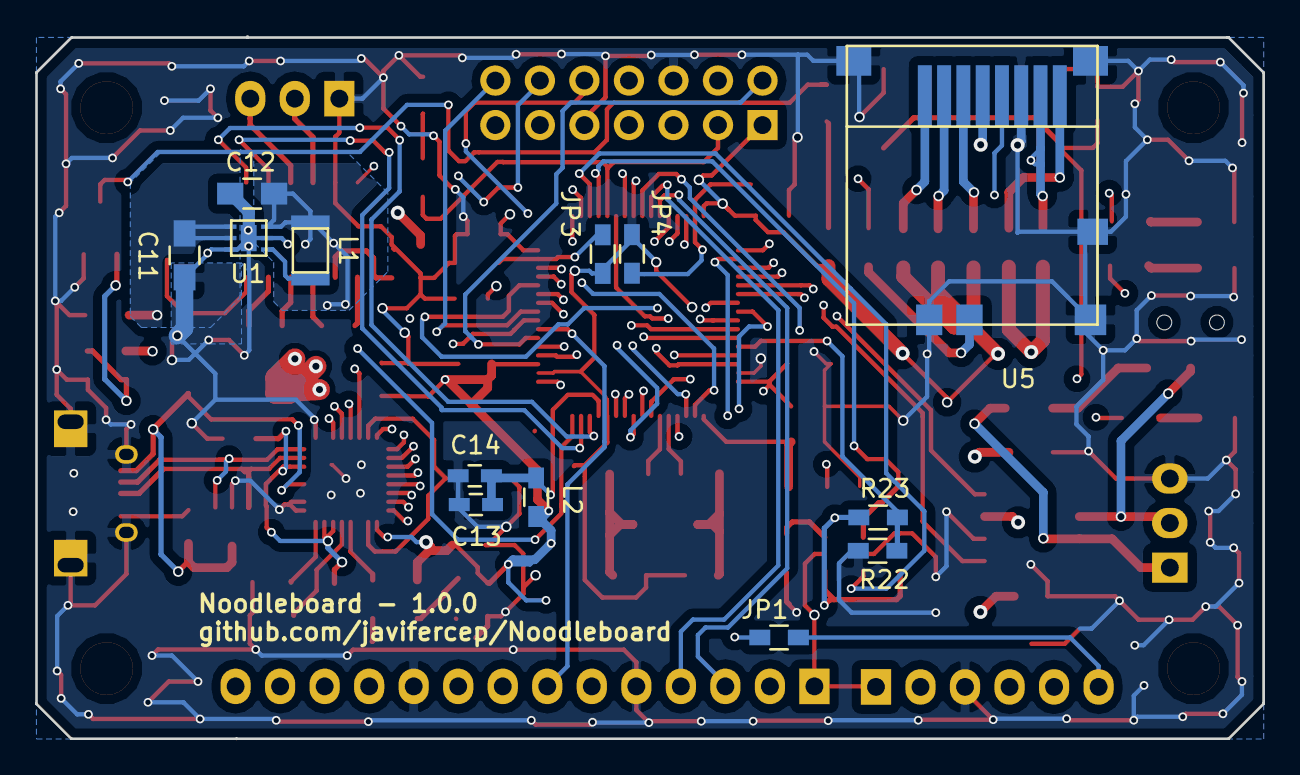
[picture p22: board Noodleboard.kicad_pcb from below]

Board: 4 copper layers, 70.0 x 40.0 mm, 91 parts (13 on the bottom side), 92 nets.

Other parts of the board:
Hole3mm, Hole3mm#2, Hole3mm#3, Hole3mm#4: VAL**; Hole3mm

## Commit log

2015-05-23 Added initial design
    [Noodleboard.csv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]
2015-10-03 #3 Add SD card interface #4 Add CAN & UART transceivers
    [B2B.sch, Boot.sch, CAN.sch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]
2015-11-07 - #4 Added UART and CAN interface transceivers - Improved schematic structure - Removed all gerber outputs - Generated schematics outputs for PCB design - Updated local libraries
    [B2B.sch, Boot.sch, CAN.sch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]
2015-11-07 - New PCB design - Updated last schematics modifications - Added Gerber outputs (old and new version)
    [Noodleboard-B_Cu.gbl, Noodleboard-B_Mask.gbs, Noodleboard-B_Paste.gbp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]
2015-11-07 Updated documentation (Sch & PCB)
    [Noodleboard.kicad_pcb, Noodleboard.sch]
2015-11-08 #5 Review USB power supply #6 Power signaling LED should be in power sheet - Simplified outputs (Gerber, sch & pcb)
    [B2B.sch, Boot.sch, CAN.sch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]
